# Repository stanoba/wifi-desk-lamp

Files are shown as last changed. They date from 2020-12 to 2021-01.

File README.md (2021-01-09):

# WiFi Controlled Desk Lamp

**WiFi Controlled Desk Lamp** project was inspired by [Twisted WiFi Controlled Desk Lamp](https://www.thingiverse.com/thing:4129249). 

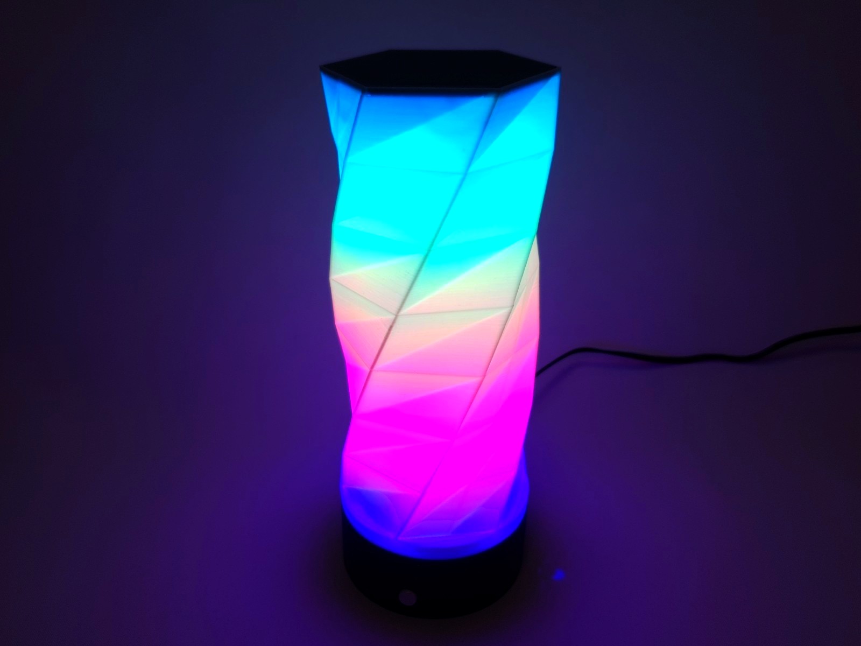
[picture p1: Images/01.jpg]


Desk Lamp includes 80 WS2812B LEDs total split in 8 segments by 10 LEDs.

## Video
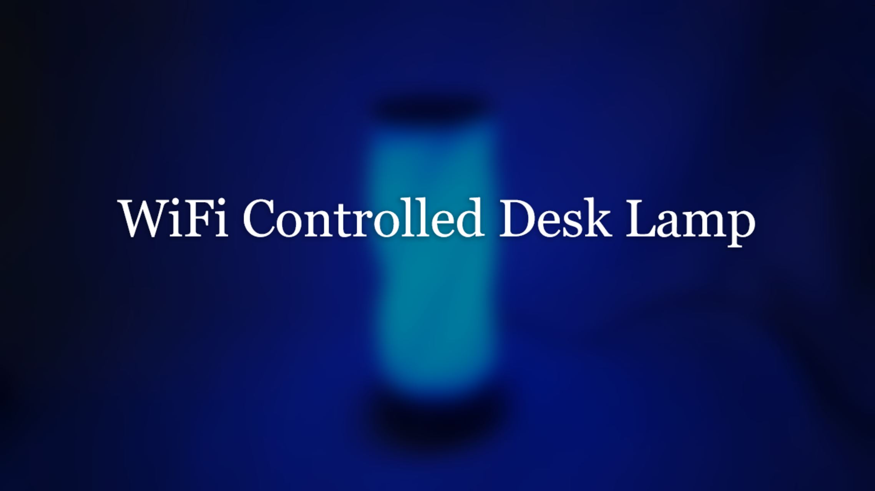
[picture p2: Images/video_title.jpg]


## Electronic
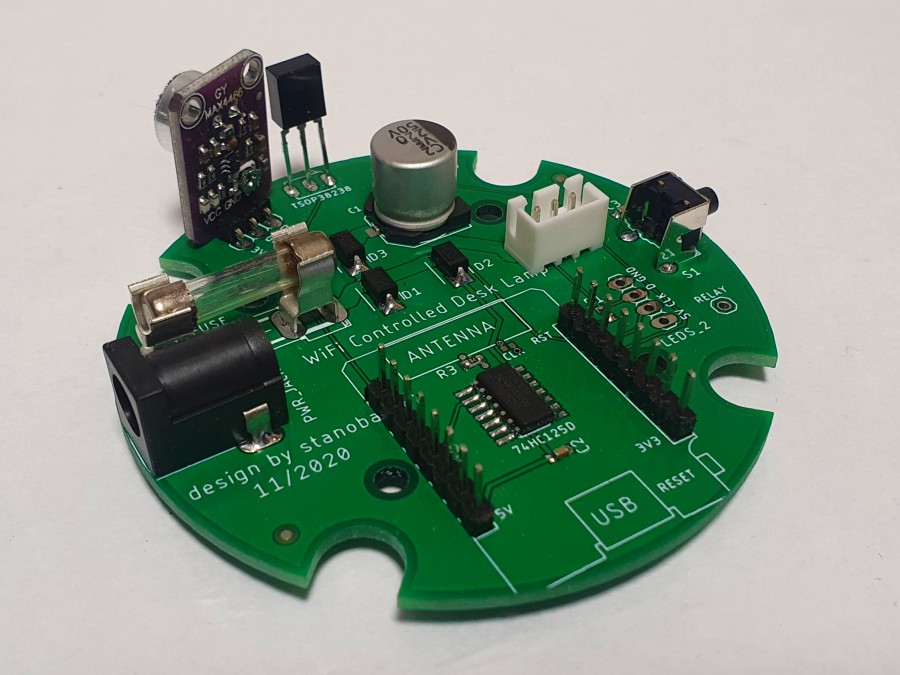
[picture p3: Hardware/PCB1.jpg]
PCB


See <a href="./Hardware">Hardware</a> README.md for more info.

## 3D printed parts
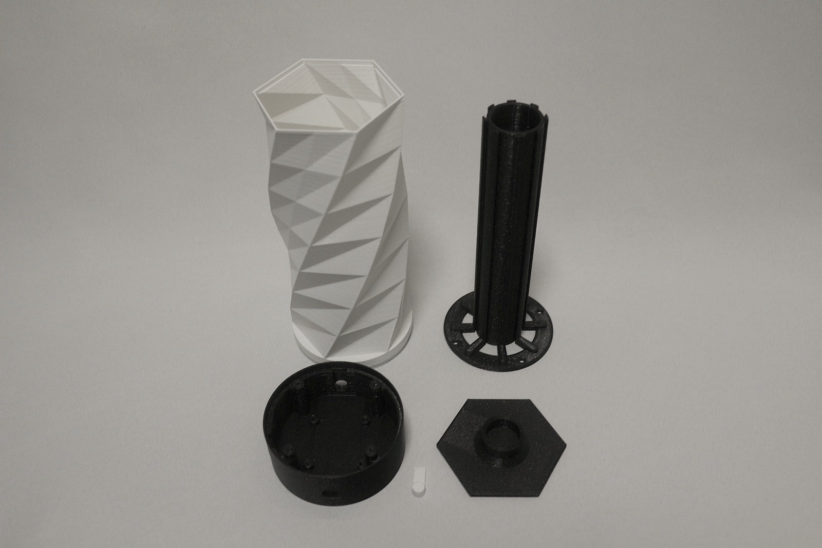
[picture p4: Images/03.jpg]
3D printed parts


See <a href="./3D models">3D models</a> README.md for more info.

## Build

### PCB in this project could be used in two ways:
---

#### 1. WiFi Controlled Desk Lamp

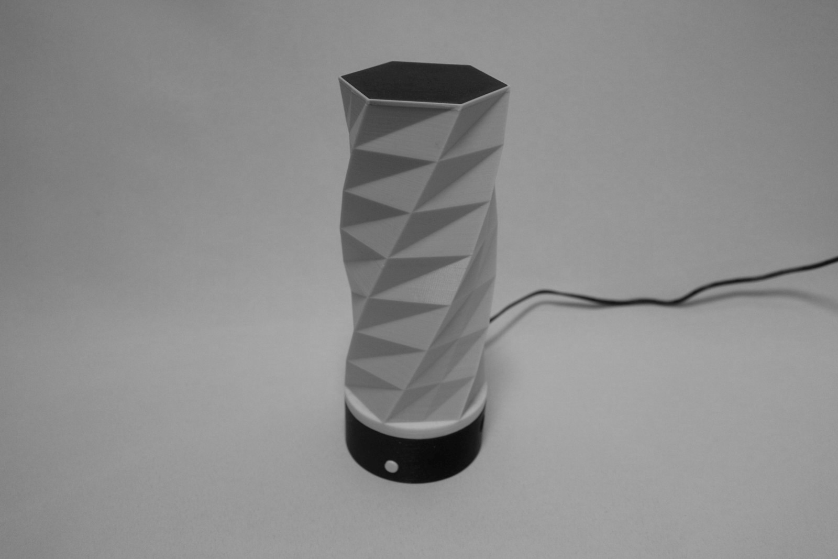
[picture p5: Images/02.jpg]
 <a href="./Images/03.jpg" target="_blank">WiFi Controlled Desk Lamp Build</a>

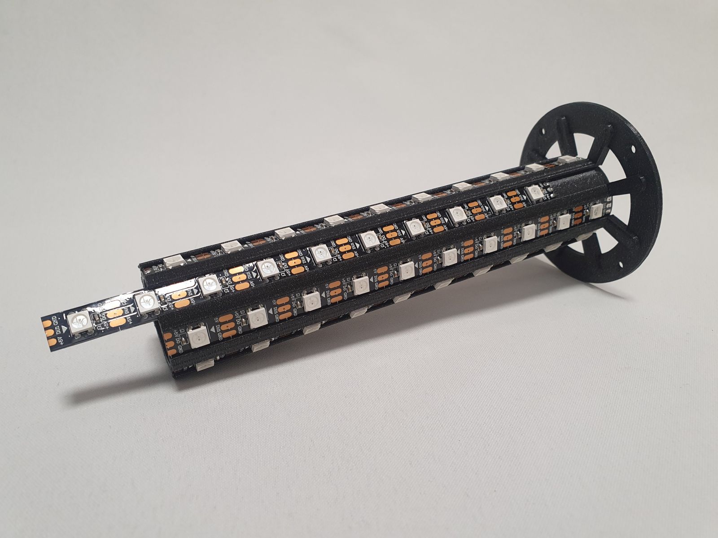
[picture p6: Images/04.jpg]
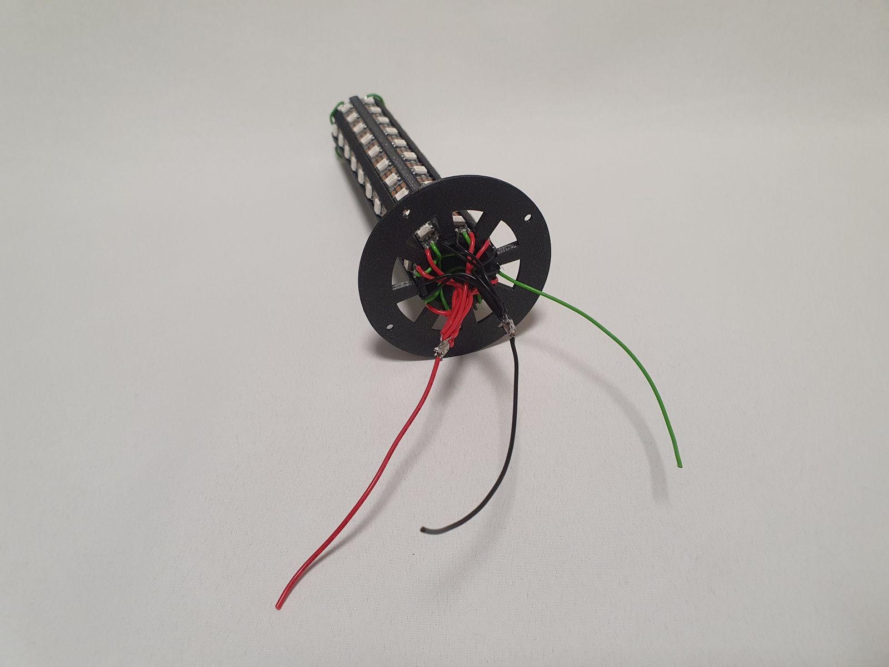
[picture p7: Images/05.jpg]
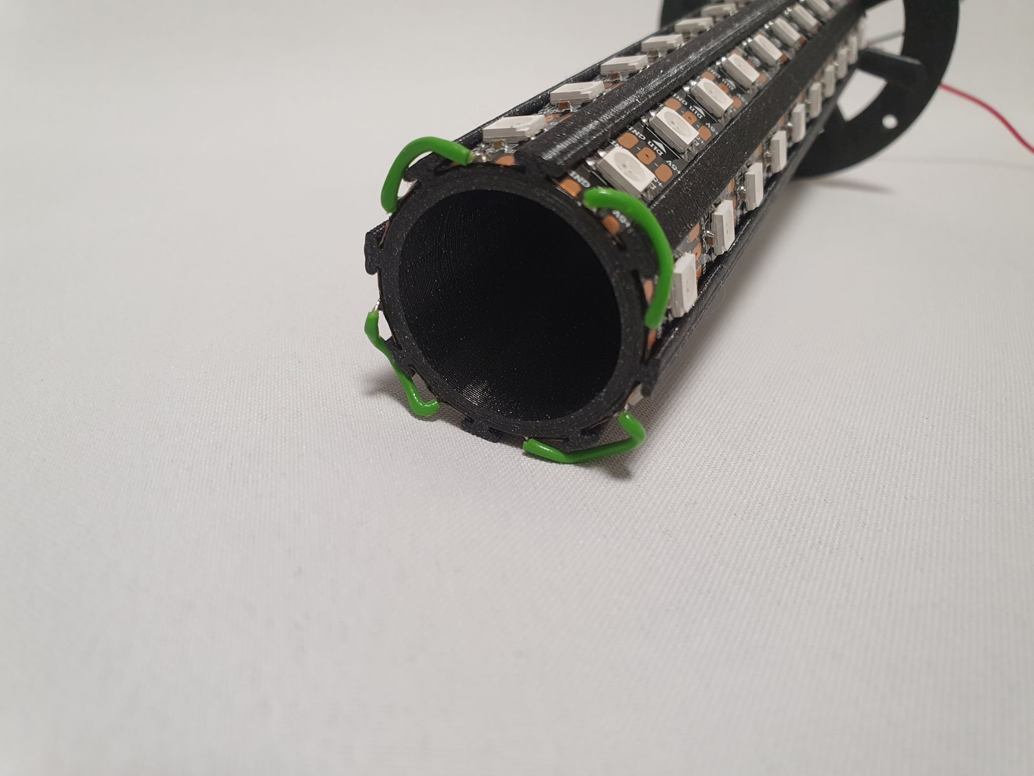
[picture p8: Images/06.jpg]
  

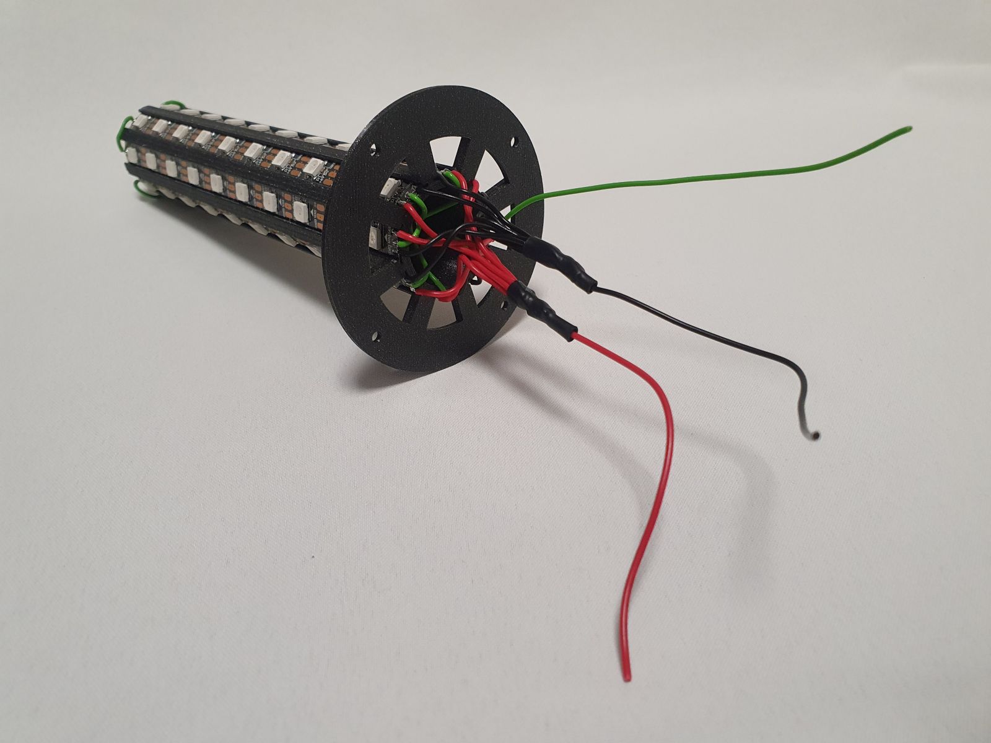
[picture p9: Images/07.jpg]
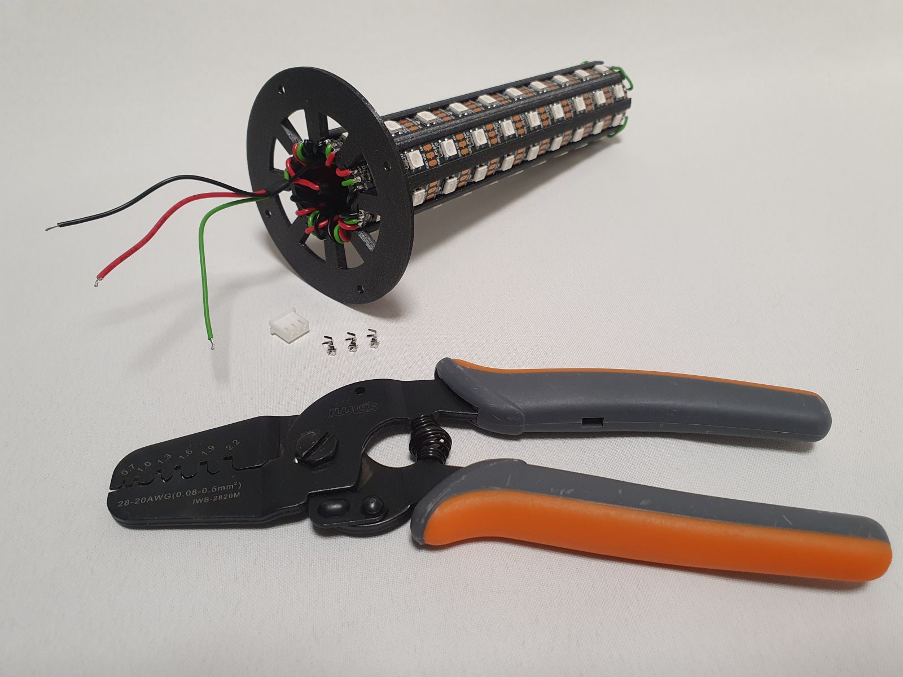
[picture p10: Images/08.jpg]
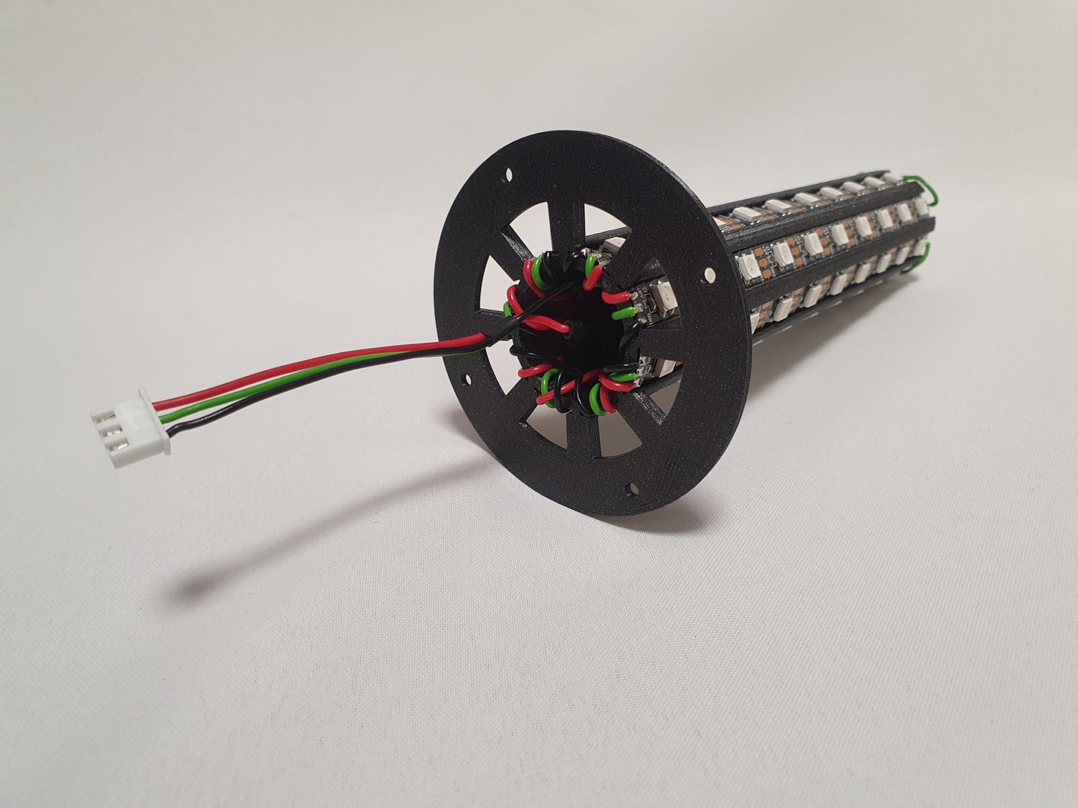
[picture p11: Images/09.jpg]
  

**BoM:**
- 1x WiFi_Controlled_Desk_Lamp_Base.stl
- 1x WiFi_Controlled_Desk_Lamp_Button.stl
- 1x WiFi_Controlled_Desk_Lamp_Core.stl
- 1x WiFi_Controlled_Desk_Lamp_Twisted_Hull.stl
- 1x WiFi_Controlled_Desk_Lamp_Twisted_Top.stl
- 1x Completed PCB
- 1x Wemos D1 mini
- 8x 170 mm LED strip WS2812B (80 LEDs total)
- 1x 5V power adapter
- 4x screws 3 x 5 mm
- 4x screws 3 x 13 mm

---
#### 2. LED stripe WiFi Controller (Puck)

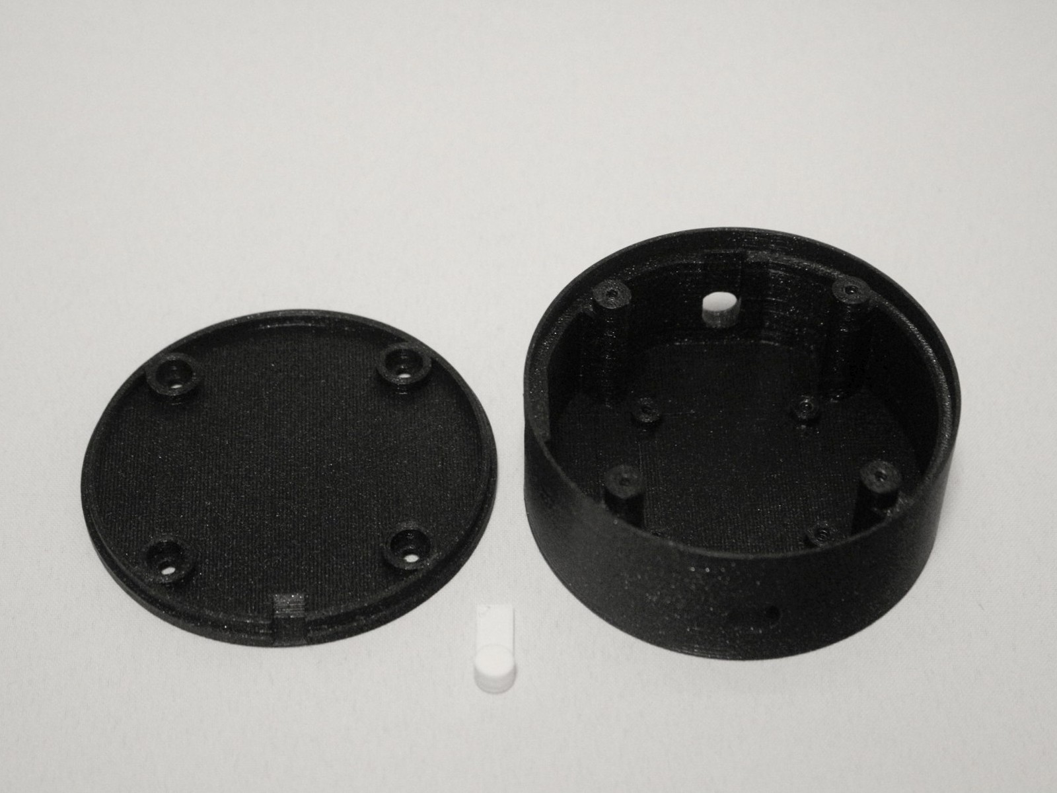
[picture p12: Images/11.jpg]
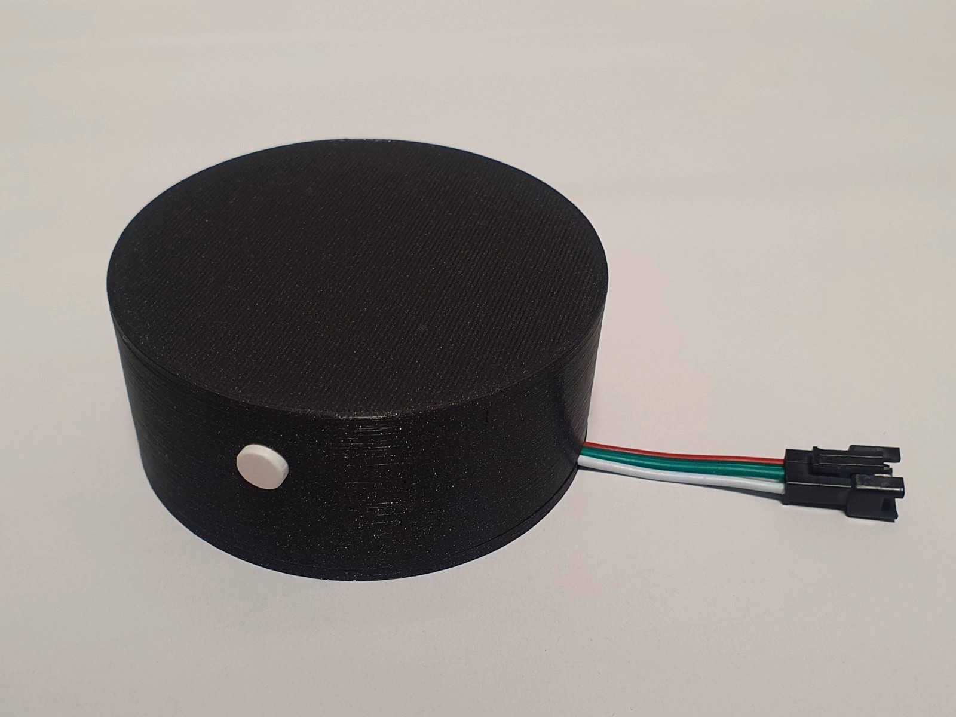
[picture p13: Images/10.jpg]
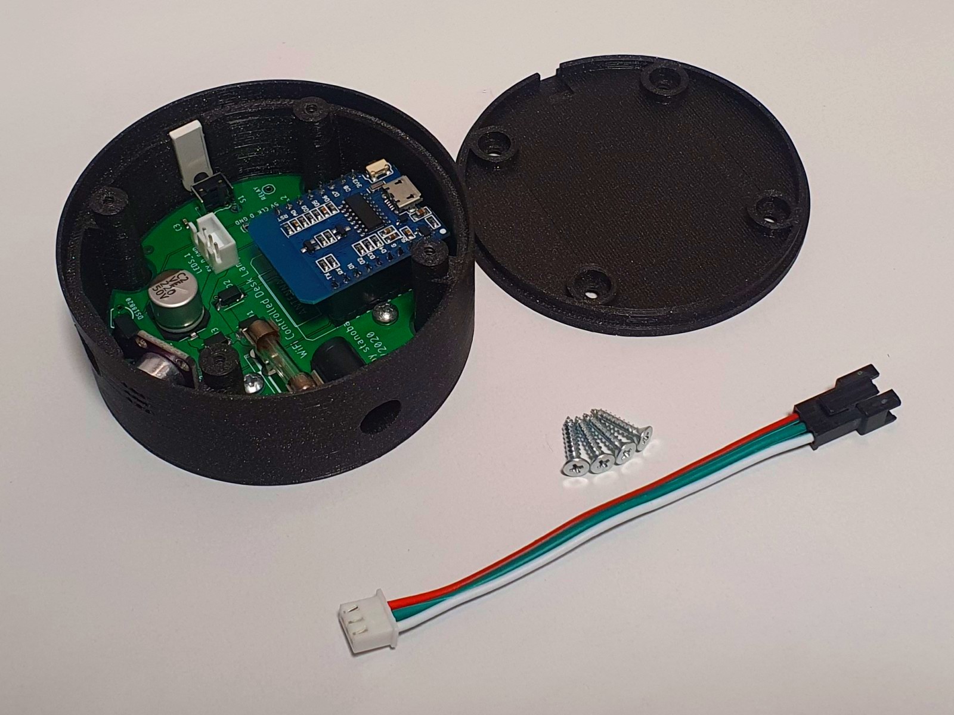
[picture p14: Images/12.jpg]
  

**BoM:**
- 1x WiFi_Controlled_Desk_Lamp_Base.stl
- 1x WiFi_Controlled_Desk_Lamp_Button.stl
- 1x WiFi_Controlled_Desk_Lamp_Top_Cover.stl
- 1x Completed PCB
- 1x Wemos D1 mini
- 1x LED strip WS2812B (based on your needs)
- 1x 5V power adapter
- 4x screws 3 x 5 mm
- 4x screws 3 x 13 mm

## Software

**WiFi Controlled Desk Lamp** was designed so it can run on [WLED](https://github.com/Aircoookie/WLED) or [WLED Sound Reactive](https://github.com/atuline/WLED) firmware.

You can also use original software [ESP8266 FastLED IoT Webserver](https://github.com/NimmLor/esp8266-fastled-iot-webserver).

See respective projects github pages for details.

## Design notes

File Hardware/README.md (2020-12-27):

# WiFi Controlled Desk Lamp - Electronic

Electronic is built around **Wemos D1 Mini** which act as brain of the desk lamp. On the PCB we can also find **74HC125D** for 3.3V-5V level-shifting, **MAX4466** as audio input and **TSOP38238** as IR input. Electronic is powered from 5V 2A power adapter and protected by ~1.6A glass fuse (depends on led stripe).

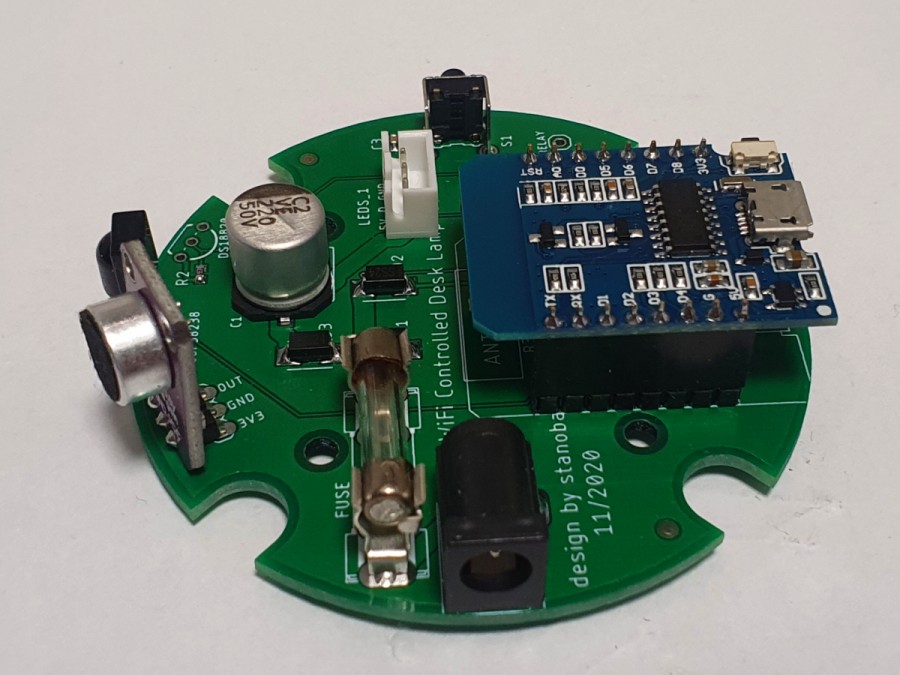
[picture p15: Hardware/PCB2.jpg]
<a href="PCB1.jpg" target="_blank">Schematic</a> 

---
## Schematic
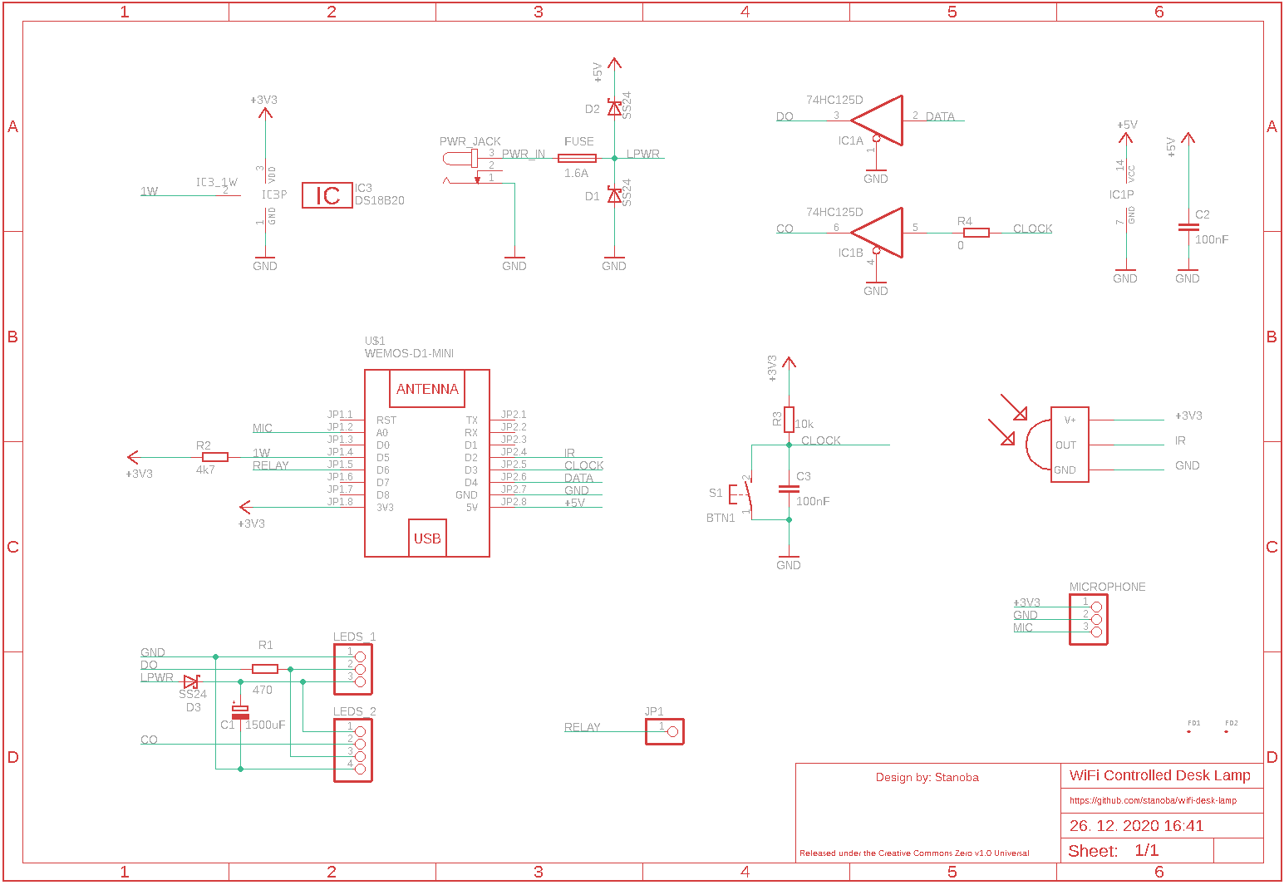
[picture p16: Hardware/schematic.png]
Schematic


## PCB

PCB was designed in Eagle 9.6.2:

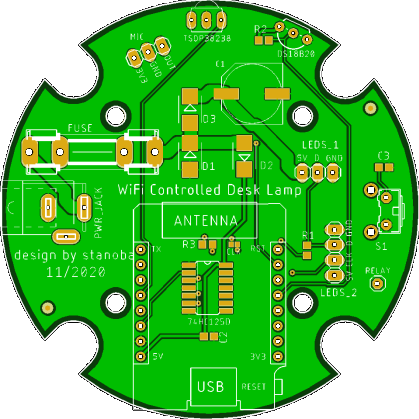
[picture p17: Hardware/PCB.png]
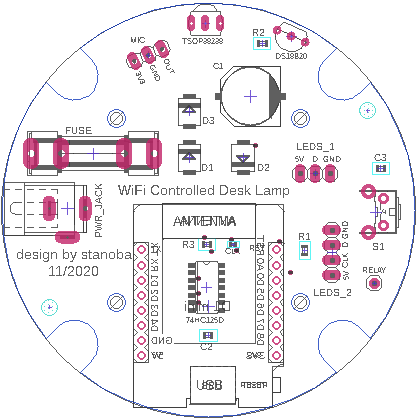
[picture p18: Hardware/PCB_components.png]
 

---

## BoM

| **Part** | **Value** | **Package** | **Source** |
| --- | --- | --- | --- |
| C1 | 1500uF | PANASONIC_G | https://www.tme.eu/en/details/eeefp0j152ap/smd-low-imped-electrolytic-capacitors/panasonic/ |
| C2, C3 | 100nF | C0603 | https://www.tme.eu/en/details/vj0603y104kxjcw1bc/0603-mlcc-smd-capacitors/vishay/ |
| R1 | 470 | R0603 | https://www.tme.eu/en/details/smd0603-470r/0603-smd-resistors/royal-ohm/0603saj0471t5e/ |
| R2 | 4k7 | R0603 | https://www.tme.eu/en/details/wf06p-4k7-5%25/0603-smd-resistors/walsin/wf06p472jtl/ |
| R3 | 10k | R0603 | https://www.tme.eu/en/details/wf06p-10k-5%25/0603-smd-resistors/walsin/wf06p103jtl/ |
| D1, D2, D3 | SS24 | SMB | https://www.tme.eu/en/details/ss24-fai/smd-schottky-diodes/on-semiconductor/ss24/ |
| FUSE | 2x clips |  | https://www.tme.eu/en/details/zh3/pcb-fuseholders/ |
| FUSE | 1.6A | 5x20 | https://www.tme.eu/en/details/zks-1.6a/fuses-5x20mm-fast/eska/520-619/ |
| IC1 | 74HC125D | SO14 | https://www.tme.eu/en/details/74hc125d.652/buffers-transceivers-drivers/nexperia/ |
| IC3 | DS18B20 | TO92 | https://www.tme.eu/en/details/ds18b20+/temperature-transducers/maxim-integrated/ |
| S1 | BTN1 | B3F-31XX | https://www.tme.eu/en/details/pts645vl58-2/microswitches-tact/c-k/pts645vl58-2-lfs/ |
| JP1 | 1X01 | pin header |
| LEDS_1 | 1X03 | pin header | https://www.tme.eu/en/details/nx2500-03sms/raster-signal-connectors-2-50mm/joint-tech/a2501wv-3p1/ |
| LEDS_2 | 1X04 | pin header | https://www.tme.eu/en/details/nx2500-04sms/raster-signal-connectors-2-50mm/joint-tech/a2501wv-4p1/ |
| MIC | 1X03 | pin header | https://www.tme.eu/en/details/ds1022-1x4rdf14/pin-headers/connfly/ds1022-1-4rdf14/ |
| PWR_JACK | SPC4077 | con-jack | https://www.tme.eu/en/details/pc-gk2.1/dc-power-connectors/ninigi/ |
| U$1 | WEMOS-D1-MINI | module | https://www.aliexpress.com/item/32651747570.html |
| U$2 | TSOP38238 | TSOP18XX | https://www.tme.eu/en/details/tsop38238/ir-receiver-modules/vishay/ |
| U$3 | MAX4466 | module | https://www.aliexpress.com/item/32607495483.html |

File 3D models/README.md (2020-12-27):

# WiFi Controlled Desk Lamp - 3D models
**WiFi Controlled Desk Lamp** was inspired by [Twisted WiFi Controlled Desk Lamp](https://www.thingiverse.com/thing:4129249).

`WiFi_Controlled_Desk_Lamp_Core`, `WiFi_Controlled_Desk_Lamp_Twisted_Hull` and `WiFi_Controlled_Desk_Lamp_Twisted_Top` are fixed/tweaked models from original project. Other models were designed in [SketchUp Make 2017](https://help.sketchup.com/en/downloading-older-versions) or [OpenSCAD](https://www.openscad.org/).

## PCB in this project could be used in two ways:
---

### 1. WiFi Controlled Desk Lamp

<a href="../Images/02.jpg" target="_blank">Schematic</a> <a href="../Images/03.jpg" target="_blank">Schematic</a>

**3D Printed parts:**
- 1x WiFi_Controlled_Desk_Lamp_Base.stl
- 1x WiFi_Controlled_Desk_Lamp_Button.stl
- 1x WiFi_Controlled_Desk_Lamp_Core.stl
- 1x WiFi_Controlled_Desk_Lamp_Twisted_Hull.stl
- 1x WiFi_Controlled_Desk_Lamp_Twisted_Top.stl

---
### 2. LED stripe WiFi Controller

<a href="../Images/10.jpg" target="_blank">Schematic</a> <a href="../Images/11.jpg" target="_blank">Schematic</a>

**3D Printed parts:**
- 1x WiFi_Controlled_Desk_Lamp_Base.stl
- 1x WiFi_Controlled_Desk_Lamp_Button.stl
- 1x WiFi_Controlled_Desk_Lamp_Top_Cover.stl

---

3D models could be also downladed from Thingiverse https://www.thingiverse.com/thing:4697599.

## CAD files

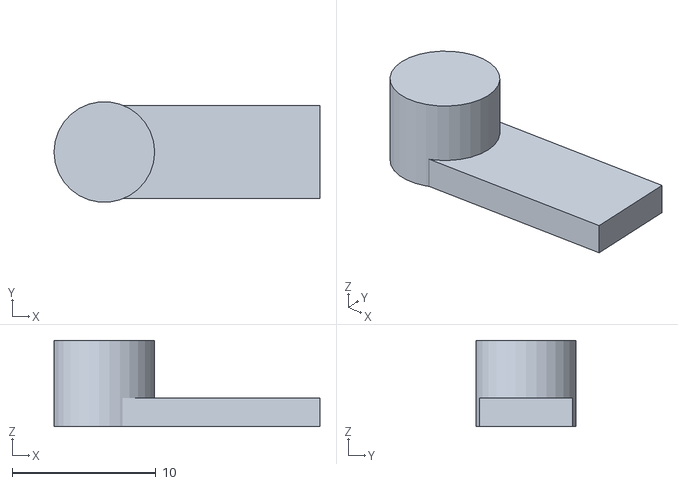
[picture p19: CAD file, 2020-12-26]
3D models/WiFi_Controlled_Desk_Lamp_Button.stl
18.5 x 6.96 x 6.00

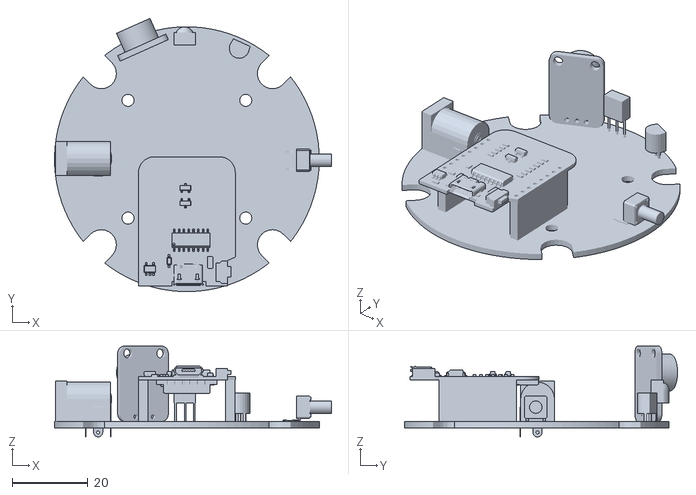
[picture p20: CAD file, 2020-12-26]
3D models/WiFi_Controlled_Desk_Lamp_PCB.stl
73.2 x 72.2 x 24.0

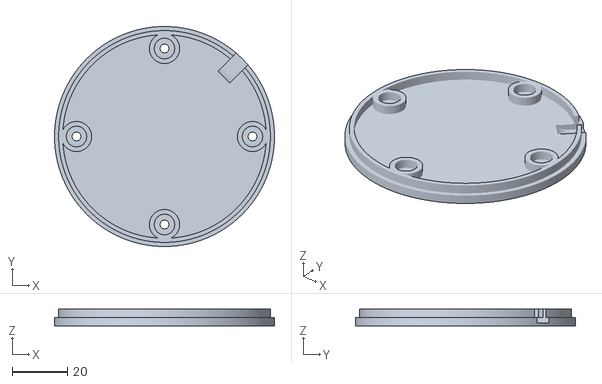
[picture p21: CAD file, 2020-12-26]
3D models/WiFi_Controlled_Desk_Lamp_Top_Cover.stl
80.0 x 80.0 x 6.00

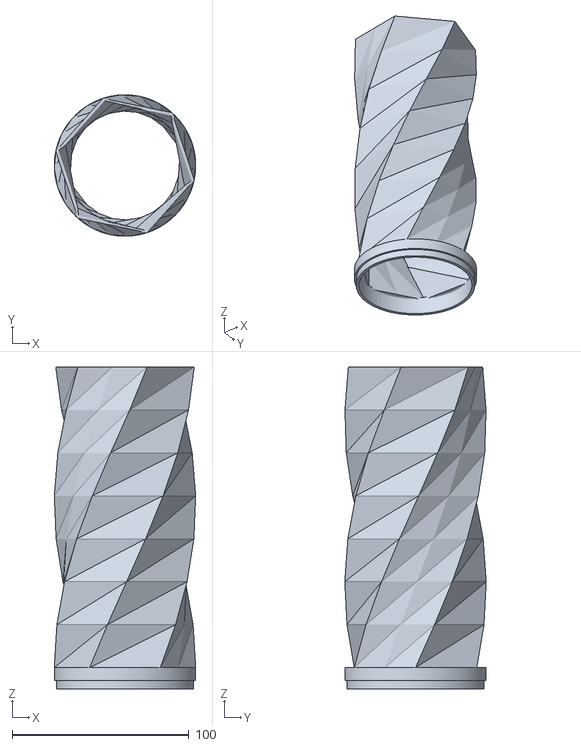
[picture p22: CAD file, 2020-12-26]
3D models/WiFi_Controlled_Desk_Lamp_Twisted_Hull.stl
80.0 x 80.0 x 182.1

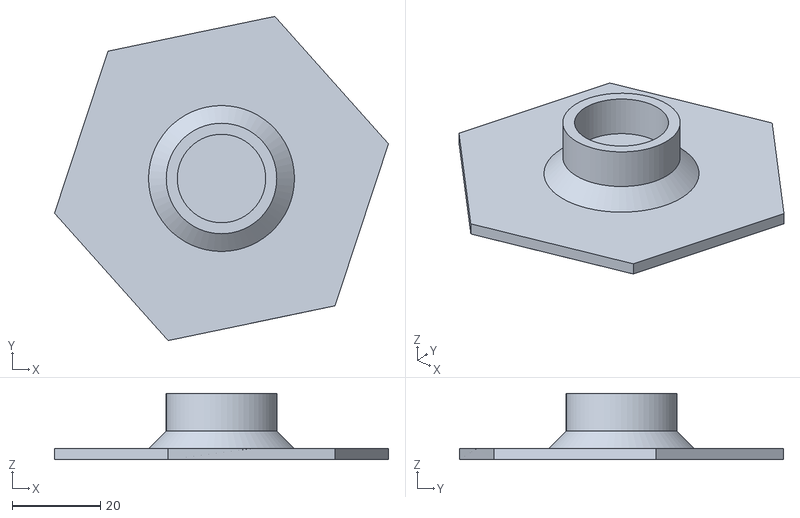
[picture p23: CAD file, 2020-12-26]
3D models/WiFi_Controlled_Desk_Lamp_Twisted_Top.stl
75.5 x 73.3 x 15.0

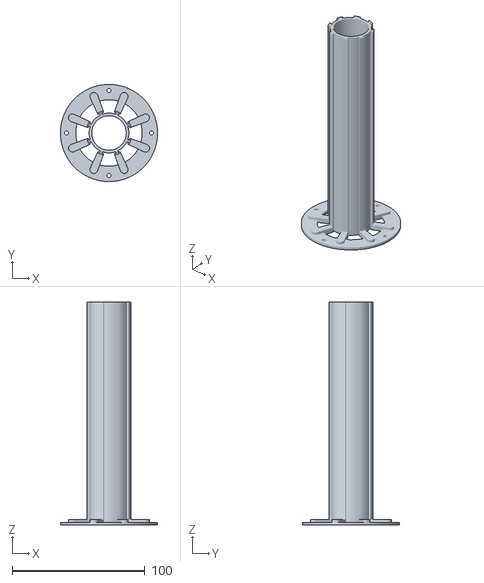
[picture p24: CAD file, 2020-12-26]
3D models/WiFi_Controlled_Desk_Lamp_Core.stl
73.2 x 73.2 x 168.0

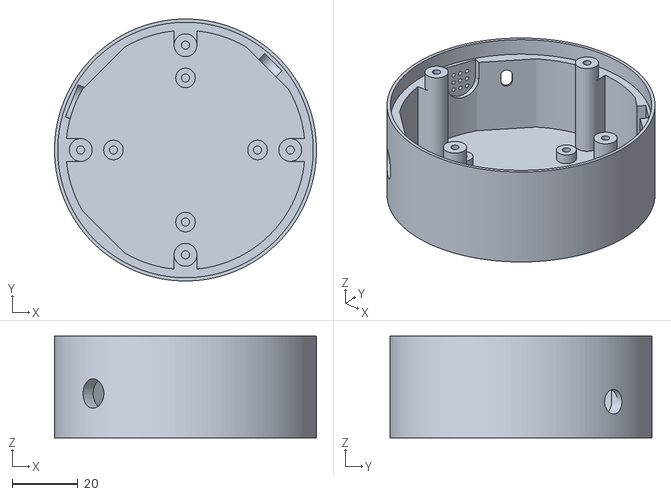
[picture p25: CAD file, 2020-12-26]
3D models/WiFi_Controlled_Desk_Lamp_Base.stl
80.0 x 80.0 x 31.0

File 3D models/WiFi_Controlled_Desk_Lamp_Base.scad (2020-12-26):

// WiFi Controlled Desk Lamp
// by stanoba http://www.thingiverse.com/stanoba/about
// https://www.thingiverse.com/thing:4697599
// https://github.com/stanoba/wifi-desk-lamp

height = 31;
width = 80;

/// PCB
//translate([0,-49.5,0]) rotate([0,0,45]) color([0,1,0]) import("PCB.stl", convexity=3);

module main(){
	difference(){
		translate([0,0,height/2]) cylinder(h = height, d = width, center = true, $fn = 160);
		translate([0,0,height-(5/2)]) cylinder(h = 5, d = width-2, center = true, $fn = 160);
		translate([0,0,(height/2)+2.5]) cylinder(h = height, d = 73, center = true, $fn = 160);
	}
	// Reinforcement - Power plug
	rotate([0,0,45]) translate([-36.9,0,13])  cube([3,19,height-5],center = true);
	
	// Reinforcement - Button
	rotate([0,0,-135]) translate([-36.9,0,13])  cube([3,19,height-5],center = true);
	
	// IR - Button
	rotate([0,0,-45]) translate([-36.9,0,13])  cube([3,19,height-5],center = true);
}

module pillars(){
	// pillars
	translate([32,0,(height/2)]) cylinder(h = height, d = 7, center = true, $fn = 30);
	translate([-32,0,(height/2)]) cylinder(h = height, d = 7, center = true, $fn = 30);
	translate([0,32,(height/2)]) cylinder(h = height, d = 7, center = true, $fn = 30);
	translate([0,-32,(height/2)]) cylinder(h = height, d = 7, center = true, $fn = 30);
	
	// pillar reinforcement
	translate([0,-35.5,(height/2)-2.5]) cube([7,7,height-5],center = true);
	translate([0,35.5,(height/2)-2.5]) cube([7,7,height-5],center = true);
	translate([-35.5,0,(height/2)-2.5]) cube([7,7,height-5],center = true);
	translate([35.5,0,(height/2)-2.5]) cube([7,7,height-5],center = true);

	// PCB pillars
	translate([22,0,(4)]) cylinder(h = 3, d = 6, center = true, $fn = 30);
	translate([-22,0,(4)]) cylinder(h = 3, d = 6, center = true, $fn = 30);
	translate([0,22,(4)]) cylinder(h = 3, d = 6, center = true, $fn = 30);
	translate([0,-22,(4)]) cylinder(h = 3, d = 6, center = true, $fn = 30);
}

module pillar_holes(){
	// pillar holes
	translate([32,0,(height/2)+2.5]) cylinder(h = height, d = 2.5, center = true, $fn = 30);
	translate([-32,0,(height/2)+2.5]) cylinder(h = height, d = 2.5, center = true, $fn = 30);
	translate([0,32,(height/2)+2.5]) cylinder(h = height, d = 2.5, center = true, $fn = 30);
	translate([0,-32,(height/2)+2.5]) cylinder(h = height, d = 2.5, center = true, $fn = 30);

	// PCB pillar holes
	translate([22,0,(4.5)]) cylinder(h = 6, d = 2.5, center = true, $fn = 20);
	translate([-22,0,(4.5)]) cylinder(h = 6, d = 2.5, center = true, $fn = 20);
	translate([0,22,(4.5)]) cylinder(h = 6, d = 2.5, center = true, $fn = 20);
	translate([0,-22,(4.5)]) cylinder(h = 6, d = 2.5, center = true, $fn = 20);
}    



///////////////////////////////////////////////////////

module cutouts(){
	// Button hole
	translate([28,28,11]) rotate([-45,90,0]) cylinder(h = 10, d = 7.5, center = true, $fn = 30);
	rotate([0,0,-135]) translate([-36,0,24])  cube([4,7.5,height-5],center = true);
	
	// Power plug
	translate([-28,-28,13.5]) rotate([-45,90,0]) cylinder(h = 10, d = 9, center = true, $fn = 30);
	
	// IR sensor
	translate([0,0,5]){
		hull(){
			translate([-28,28,16]) rotate([45,90,0]) cylinder(h = 7, d1 = 14, d2 = 3.5, center = true, $fn = 30);
			translate([-28,28,14]) rotate([45,90,0]) cylinder(h = 7, d1 = 14, d2 = 3.5, center = true, $fn = 30);
		}
		hull(){
			translate([-28,28,16]) rotate([45,90,0]) cylinder(h = 15, d = 3.5, center = true, $fn = 30);
			translate([-28,28,14]) rotate([45,90,0]) cylinder(h = 15, d = 3.5, center = true, $fn = 30);
		}
	}
	// Microphone
	translate([-31,13.5,20.3]) rotate([22,90,0]) cylinder(h = 8, d = 10.5, center = true, $fn = 30);
	translate([-31,13.5,23.2]) rotate([22,90,0]) cube([6,10.5,8],center = true);
	
	// Microphone holes
	translate([-31,13.5,20.3]) rotate([22,90,0]) cylinder(h = 15, d = 1.2, center = true, $fn = 30);
	translate([-31,16,20.3]) rotate([22,90,0]) cylinder(h = 15, d = 1.2, center = true, $fn = 30);
	translate([-31,11,20.3]) rotate([22,90,0]) cylinder(h = 15, d = 1.2, center = true, $fn = 30);
	
	translate([-31,13.5,22.8]) rotate([22,90,0]) cylinder(h = 15, d = 1.2, center = true, $fn = 30);
	translate([-31,16,22.8]) rotate([22,90,0]) cylinder(h = 15, d = 1.2, center = true, $fn = 30);
	translate([-31,11,22.8]) rotate([22,90,0]) cylinder(h = 15, d = 1.2, center = true, $fn = 30);

	translate([-31,13.5,17.8]) rotate([22,90,0]) cylinder(h = 15, d = 1.2, center = true, $fn = 30);
	translate([-31,16,17.8]) rotate([22,90,0]) cylinder(h = 15, d = 1.2, center = true, $fn = 30);
	translate([-31,11,17.8]) rotate([22,90,0]) cylinder(h = 15, d = 1.2, center = true, $fn = 30);

	
	
}

difference(){
	union(){
		pillars();
		main();
	}
	pillar_holes();
	cutouts();    
}

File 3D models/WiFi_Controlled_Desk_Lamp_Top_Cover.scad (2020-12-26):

// WiFi Controlled Desk Lamp
// by stanoba http://www.thingiverse.com/stanoba/about
// https://www.thingiverse.com/thing:4697599
// https://github.com/stanoba/wifi-desk-lamp

height = 3; //22.5;
width = 80;

module main(){
	difference(){
		union(){
			translate([0,0,height/2]) cylinder(h = height, d = width, center = true, $fn = 160);
			translate([0,0,(height/2)+3]) cylinder(h = 3, d = width-3 , center = true, $fn = 160);
		}
		translate([0,0,(height/2)+3]) cylinder(h = 3, d = width-6, center = true, $fn = 160);
	}
}

module pillars(){
	// pillars
	translate([32,0,(height/2)+height])  cylinder(h = height, d = 11, center = true, $fn = 30);
	translate([-32,0,(height/2)+height]) cylinder(h = height, d = 11, center = true, $fn = 30);
	translate([0,32,(height/2)+height])  cylinder(h = height, d = 11, center = true, $fn = 30);
	translate([0,-32,(height/2)+height]) cylinder(h = height, d = 11, center = true, $fn = 30);
}

module pillar_holes(){
	// pillar holes
	translate([32,0,(height/2)]) cylinder(h = height, d = 3.2, center = true, $fn = 30);
	translate([-32,0,(height/2)]) cylinder(h = height, d = 3.2, center = true, $fn = 30);
	translate([0,32,(height/2)]) cylinder(h = height, d = 3.2, center = true, $fn = 30);
	translate([0,-32,(height/2)]) cylinder(h = height, d = 3.2, center = true, $fn = 30);
	
	translate([32,0,1]) cylinder(h = 2, d1 = 6, d2 = 3.2, center = true, $fn = 30);
	translate([-32,0,1]) cylinder(h = 2, d1 = 6, d2 = 3.2, center = true, $fn = 30);
	translate([0,32,1]) cylinder(h = 2, d1 = 6, d2 = 3.2, center = true, $fn = 30);
	translate([0,-32,1]) cylinder(h = 2, d1 = 6, d2 = 3.2, center = true, $fn = 30);
	
	
	// pillar big holes
	translate([32,0,(height/2)+height]) cylinder(h = height, d = 7.5, center = true, $fn = 30);
	translate([-32,0,(height/2)+height]) cylinder(h = height, d = 7.5, center = true, $fn = 30);
	translate([0,32,(height/2)+height]) cylinder(h = height, d = 7.5, center = true, $fn = 30);
	translate([0,-32,(height/2)+height]) cylinder(h = height, d = 7.5, center = true, $fn = 30);
}    



///////////////////////////////////////////////////////

module cutouts(){
	// Cable hole
	rotate([0,0,45]){
		translate([width/2,0,(height/2)+0.5+14]) cube([10,6,30],center = true);
		translate([(width/2)-5,0,(height/2)+0.5+5]) rotate([90,90,0]) cylinder(h = 6, d = 12, center = true, $fn = 60);
	}
}

difference(){
	union(){
		pillars();
		main();
	}
	pillar_holes();   
	cutouts();
}

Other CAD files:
3D models/WiFi_Controlled_Desk_Lamp_Button.scad
3D models/WiFi_Controlled_Desk_Lamp_Core.skp
3D models/WiFi_Controlled_Desk_Lamp_Twisted_Hull.skp
3D models/WiFi_Controlled_Desk_Lamp_Twisted_Top.skp

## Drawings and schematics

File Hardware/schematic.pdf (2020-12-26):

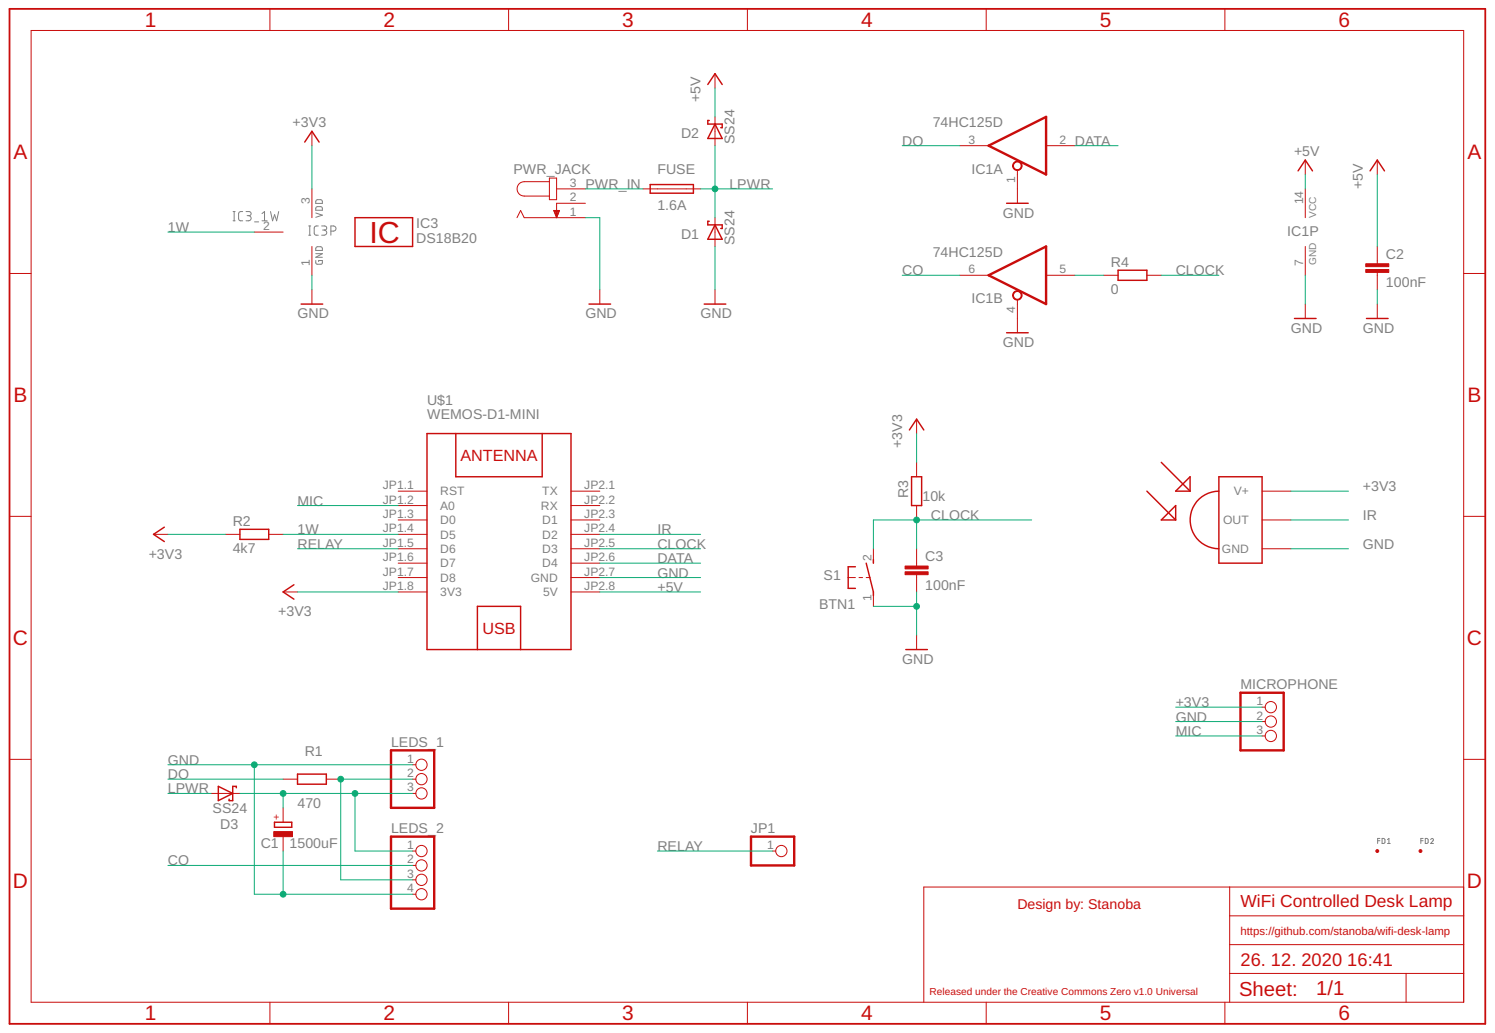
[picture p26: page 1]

https://github.com/stanoba/wifi-desk-lamp Design by: Stanoba

WiFi Controlled Desk Lamp

Released under the Creative Commons Zero v1.0 Universal

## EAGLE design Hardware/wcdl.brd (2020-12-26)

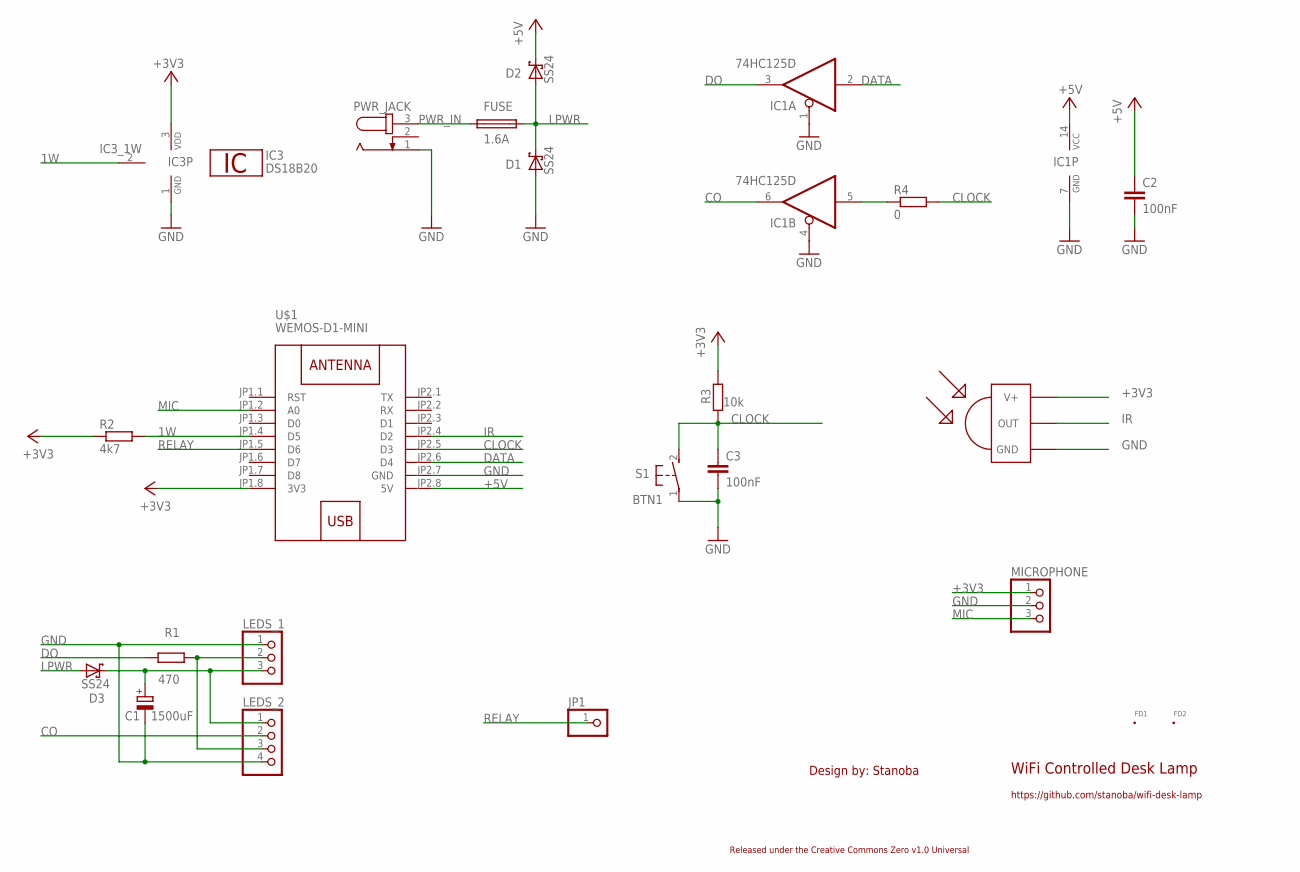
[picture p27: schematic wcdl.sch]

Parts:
C1: 1500uF; PANASONIC_G
C2, C3: 100nF; C0603
D1, D2, D3: SS24; SMB
FD1, FD2: FID_40MIL; FID_040
FUSE: 1.6A; SHK20L
IC1: 74HC125D; SO14
IC3: DS18B20; TO92-
JP1: PINHD-1X1; 1X01
LEDS_1: PINHD-1X3; 1X03
LEDS_2: PINHD-1X4; 1X04
MICROPHONE: PINHD-1X3; 1X03
PWR_JACK: JACK-PLUG0; SPC4077
R1: 470; R0603
R2: 4k7; R0603
R3: 10k; R0603
R4: 0; R0402
S1: BTN1; B3F-31XX
U$1: WEMOS-D1-MINI
U$2: TSOP1838; TSOP18XX

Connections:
1W: IC3.2 (1W), R2.2, U$1.JP1.4 (D5)
+3V3: IC3.3 (VDD), MICROPHONE.1, R2.1, R3.2, U$1.JP1.8 (3V3), U$2.VCC (V+)
+5V: C2.1, D2.C, IC1.14 (VCC), U$1.JP2.8 (5V)
CLOCK: C3.1, R3.1, R4.2, S1.2 (S), U$1.JP2.5 (D3)
CO: IC1.6 (O), LEDS_2.2
DATA: IC1.2 (I), U$1.JP2.6 (D4)
DO: IC1.3 (O), R1.1
GND: C1.-, C2.2, C3.2, D1.A, IC1.1 (OE), IC1.4 (OE), IC1.7 (GND), IC3.1 (GND), LEDS_1.1, LEDS_2.4, MICROPHONE.2, PWR_JACK.1, S1.1, U$1.JP2.7 (GND), U$2.GND
IR: U$1.JP2.4 (D2), U$2.OUT
LPWR: D1.C, D2.A, D3.A, FUSE.2A (2)
MIC: MICROPHONE.3, U$1.JP1.2 (A0)
unnamed: C1.+, D3.C, LEDS_1.3, LEDS_2.1
unnamed: LEDS_1.2, LEDS_2.3, R1.2
unnamed: IC1.5 (I), R4.1
PWR_IN: FUSE.1A (1), PWR_JACK.3
RELAY: JP1.1, U$1.JP1.5 (D6)

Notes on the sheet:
WiFi Controlled Desk Lamp
https://github.com/stanoba/wifi-desk-lamp
Design by: Stanoba
Released under the Creative Commons Zero v1.0 Universal

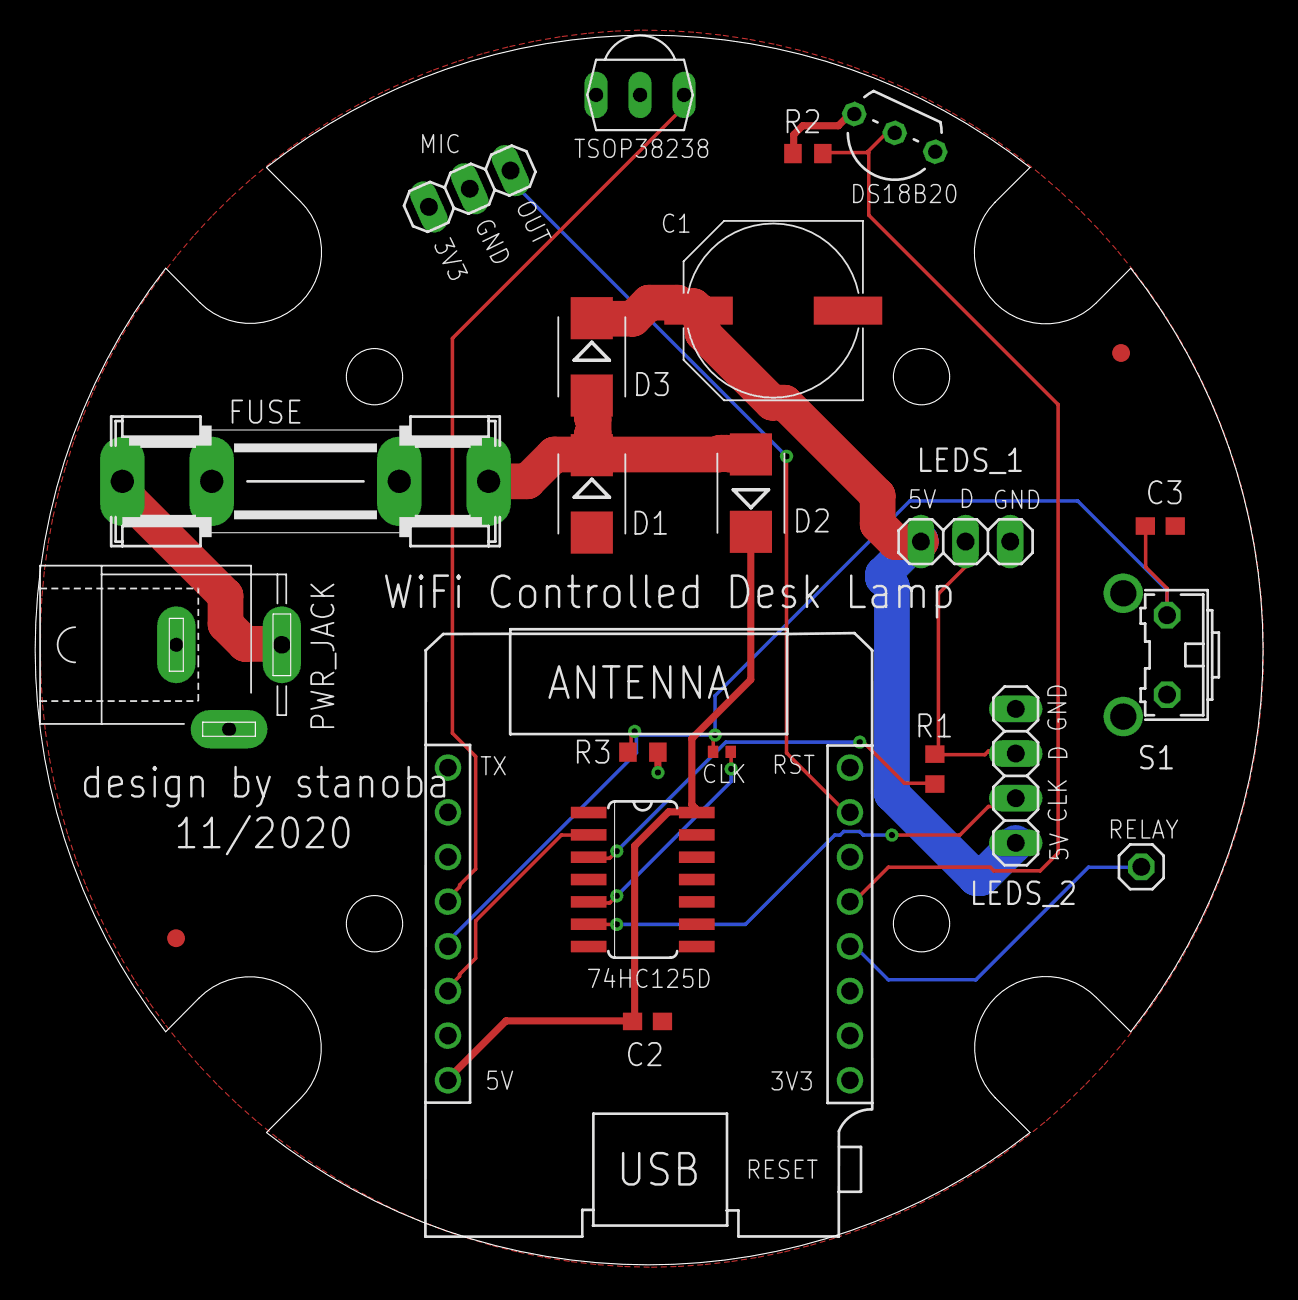
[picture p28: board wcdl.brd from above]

Board: 2 copper layers, 69.8 x 69.9 mm, 23 parts (1 on the bottom side), 16 nets.

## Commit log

2020-12-26 First project upload
    [WiFi_Controlled_Desk_Lamp_Base.scad, WiFi_Controlled_Desk_Lamp_Base.stl, WiFi_Controlled_Desk_Lamp_Button.scad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]
2020-12-27 Added sources to BoM

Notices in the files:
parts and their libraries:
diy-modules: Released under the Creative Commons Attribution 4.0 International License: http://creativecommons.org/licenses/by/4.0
